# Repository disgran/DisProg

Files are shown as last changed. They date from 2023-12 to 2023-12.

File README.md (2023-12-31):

# DisProg™

DisProg™ es una placa de adaptador USB a serie que se fundamenta en el popular chip CP2102N, incluyendo un circuito de restablecimiento automático ESP32. A diferencia de los módulos económicos que puedes encontrar en Aliexpress, este adaptador destaca por su confiabilidad y versatilidad simultánea. Su confiabilidad se deriva del uso de un conocido chip de adaptador USB a serie proveniente de un proveedor reconocido, y su versatilidad radica en la inclusión del circuito de restablecimiento automático ESP32 IO & EN, eliminando la necesidad de implementarlo en la placa de destino.

Otro punto a favor de DisProg™ es su regulador de voltaje integrado de 3.3V y 500mA, capaz de alimentar el dispositivo que estás programando. Como opción adicional, puedes conectar un cable JST personalizado que facilita la programación segura de relés Shelly sin depender de la alimentación principal. Esto sitúa a DisProg™ como uno de los mejores adaptadores USB/serie para cargar el firmware de tus dispositivos con Tasmota o ESPHome.

Para obtener más detalles sobre este proyecto, te invito a consultar la entrada correspondiente en https://disgran.com/disprog.

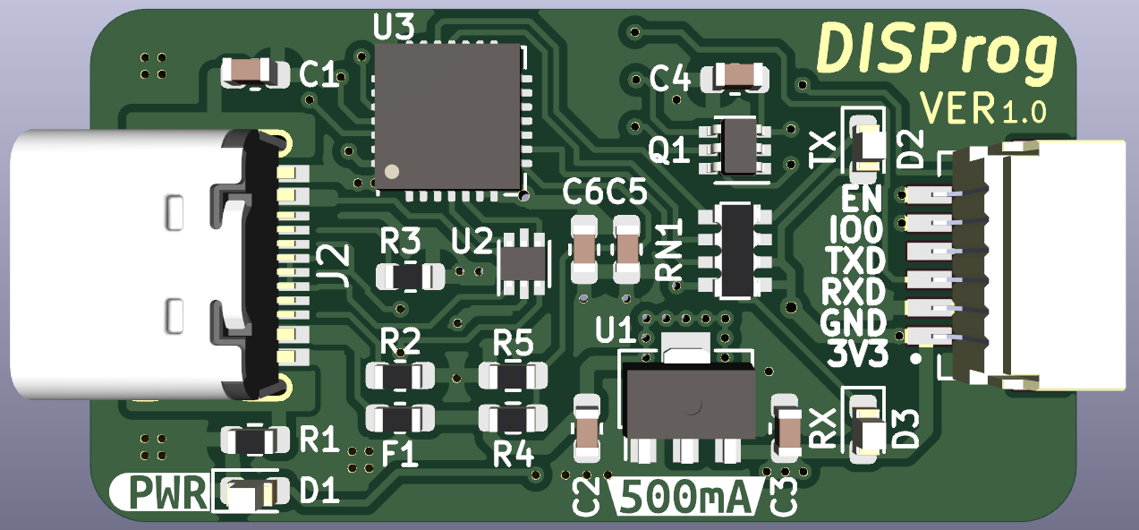
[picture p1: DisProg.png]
Preview_PCB_Terminada


Si estás interesado en adquirir uno de estos adaptadores preensamblados, te invito a visitar mi tienda en https://disgran.com

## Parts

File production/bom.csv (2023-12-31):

Designator | Footprint | Quantity | Value
C1 | 0805 | 1 | 4.7nF
C2 | 0603 | 1 | 1uF
C3 | 0603 | 1 | 10uF
C4 | 0603 | 1 | 1uF
C5 | 0603 | 1 | 10uF
C6 | 0603 | 1 | 0.1uF
D1 | 0603 | 1 | PWR
D2 | 0603 | 1 | TX
D3 | 0603 | 1 | RX
F1 | 0603 | 1 | 0.5A
J1 | JST_SM06B-SRSS-TB_LF__SN_ | 1 | Con_Prog
J2 | USB_C_Receptacle_HRO_TYPE-C-31-M-12 | 1 | USB C
Q1 | SOT-363_SC-70-6 | 1 | UMH3N
R1 | 0603 | 1 | 1M
R2, R3 | 0603 | 2 | 5K1
R4 | 0603 | 1 | 22.1K
R5 | 0603 | 1 | 47.5K
RN1 | R_Array_Convex_4x0603 | 1 | 1K
U1 | SOT-89-3 | 1 | LR1107
U2 | SOT-666 | 1 | USBLC6-2P6
U3 | QFN-28-1EP_5x5mm_P0.5mm_EP3.35x3.35mm | 1 | CP2102N

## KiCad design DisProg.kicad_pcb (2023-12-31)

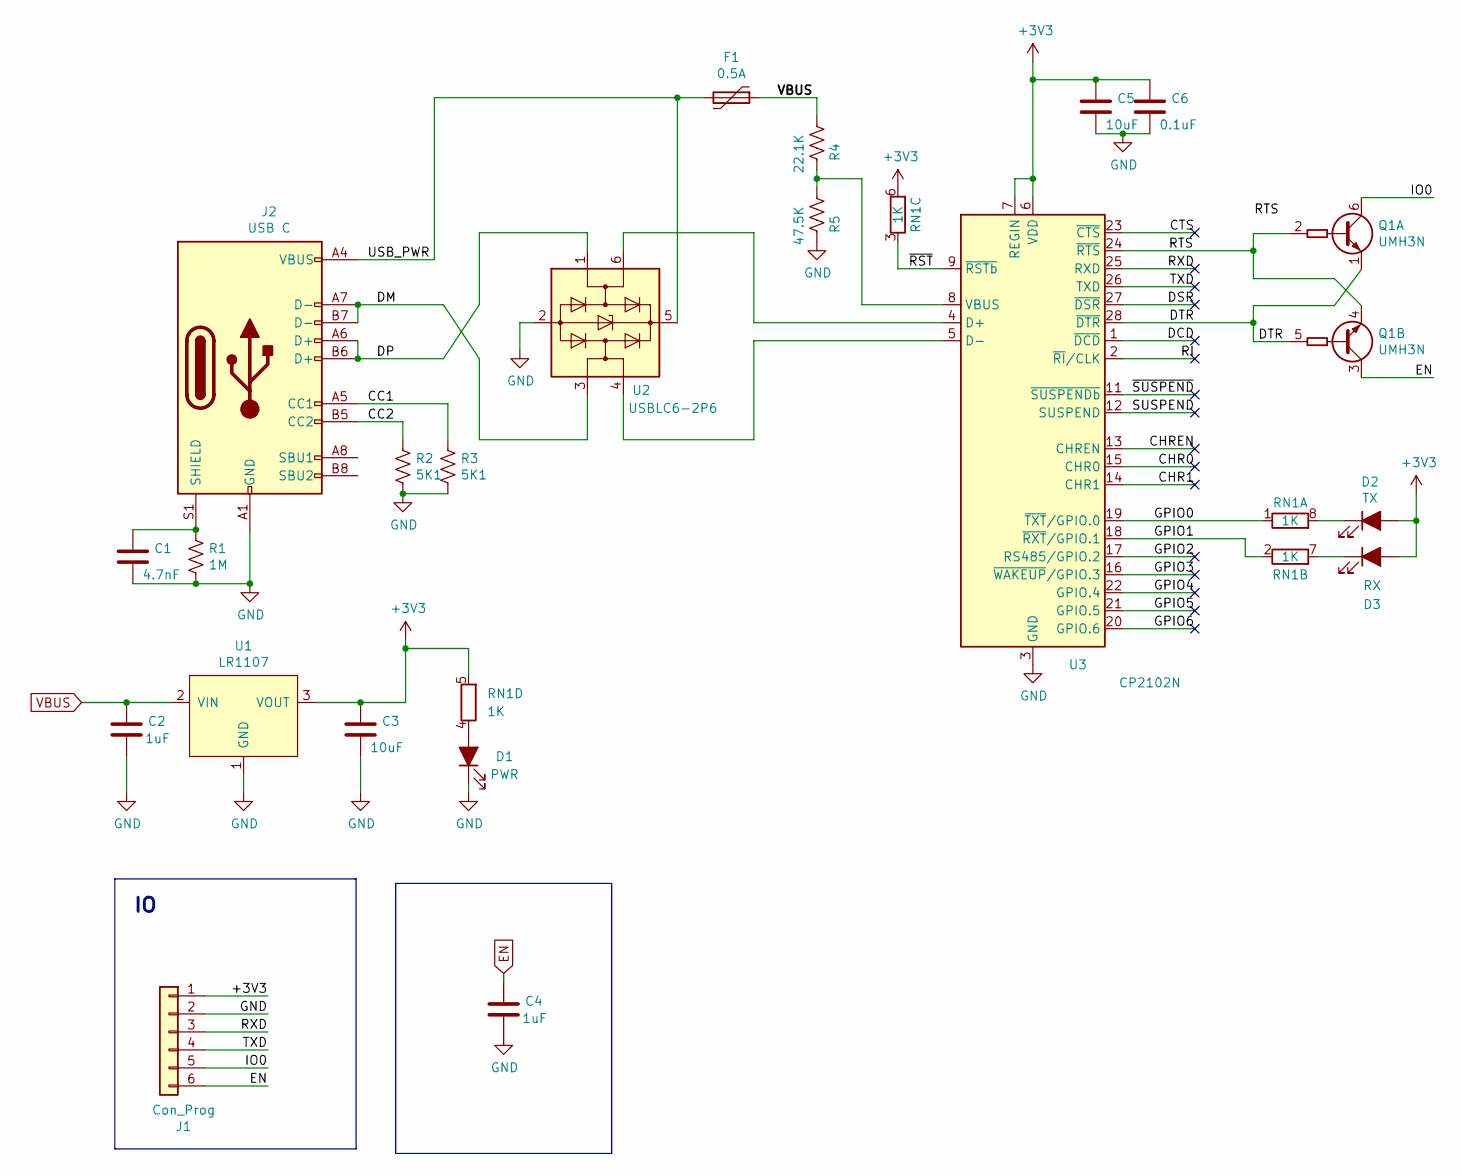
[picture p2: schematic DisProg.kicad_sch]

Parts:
C1: 4.7nF; C_0805_2012Metric; Voltage 50V; LCSC C53987
C2: 1uF; C_0603_1608Metric; LCSC C15849
C3: 10uF; C_0603_1608Metric; LCSC C96446
C4: 1uF; C_0603_1608Metric
C5: 10uF; C_0603_1608Metric; LCSC C19702
C6: 0.1uF; C_0603_1608Metric; LCSC C14663
D1: PWR; LED_0603_1608Metric; LCSC C2286
D2: TX; LED_0603_1608Metric; LCSC C72043
D3: RX; LED_0603_1608Metric; LCSC C2286
F1: 0.5A; Fuse_0603_1608Metric; LCSC C207014
J1: Con_Prog; JST_SM06B-SRSS-TB_LF__SN_; LCSC C160405
J2: USB C; USB_C_Receptacle_HRO_TYPE-C-31-M-12; LCSC C165948
Q1: UMH3N; SOT-363_SC-70-6; LCSC C62892
R1: 1M; R_0603_1608Metric; LCSC C2090547
R2, R3: 5K1; R_0603_1608Metric
R4: 22.1K; R_0603_1608Metric
R5: 47.5K; R_0603_1608Metric
RN1: 1K; R_Array_Convex_4x0603
U1: LR1107; SOT-89-3; LCSC C171498
U2: USBLC6-2P6; SOT-666
U3: CP2102N; QFN-28-1EP_5x5mm_P0.5mm_EP3.35x3.35mm; LCSC C964632

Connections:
+3V3: C3.1, C5.1, C6.1, D2.2 (A), D3.2 (A), J1.1, RN1.5 (R4.2), RN1.6 (R3.2), U1.3 (VOUT), U3.6 (VDD), U3.7 (REGIN)
/CC1: J2.A5 (CC1), R3.1
/CC2: J2.B5 (CC2), R2.1
/CHR0: U3.15 (CHR0)
/CHR1: U3.14 (CHR1)
/CHREN: U3.13 (CHREN)
/CTS: U3.23 (~CTS)
/DCD: U3.1 (~DCD)
/DM: J2.A7 (D-), J2.B7 (D-), U2.3 (I/O2)
/DP: J2.A6 (D+), J2.B6 (D+), U2.1 (I/O1)
/DSR: U3.27 (~DSR)
/DTR: Q1.1 (E1), Q1.5 (B2), U3.28 (~DTR)
/GPIO0: RN1.1 (R1.1), U3.19 (~TXT/GPIO.0)
/GPIO1: RN1.2 (R2.1), U3.18 (~RXT/GPIO.1)
/GPIO2: U3.17 (RS485/GPIO.2)
/GPIO3: U3.16 (~WAKEUP/GPIO.3)
/GPIO4: U3.22 (GPIO.4)
/GPIO5: U3.21 (GPIO.5)
/GPIO6: U3.20 (GPIO.6)
/IO0: J1.5, Q1.6 (C1)
/RI: U3.2 (~RI/CLK)
/RTS: Q1.2 (B1), Q1.4 (E2), U3.24 (~RTS)
/RXD: J1.3, U3.25 (RXD)
/SUSPEND: U3.12 (SUSPEND)
/TXD: J1.4, U3.26 (TXD)
/USB_PWR: F1.2, J2.A4 (VBUS), J2.A9 (VBUS), J2.B4 (VBUS), J2.B9 (VBUS), U2.5 (VBUS)
/~RST: RN1.3 (R3.1), U3.9 (~RSTb)
/~SUSPEND: U3.11 (~SUSPENDb)
EN: C4.1, J1.6, Q1.3 (C2)
GND: C1.2, C2.2, C3.2, C4.2, C5.2, C6.2, D1.1 (K), J1.2, J2.A1 (GND), J2.A12 (GND), J2.B1 (GND), J2.B12 (GND), R1.2, R2.2, R3.2, R5.2, U1.1 (GND), U2.2 (GND), U3.3 (GND), U3.29 (GND)
unnamed: D1.2 (A), RN1.4 (R4.1)
unnamed: D2.1 (K), RN1.8 (R1.2)
unnamed: D3.1 (K), RN1.7 (R2.2)
unnamed: C1.1, J2.S1 (SHIELD), R1.1
unnamed: U2.6 (I/O1), U3.4 (D+)
unnamed: U2.4 (I/O2), U3.5 (D-)
unnamed: R4.2, R5.1, U3.8 (VBUS)
VBUS: C2.1, F1.1, R4.1, U1.2 (VIN)

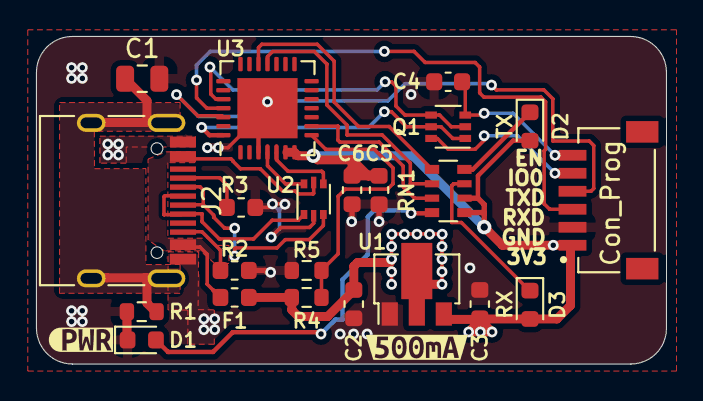
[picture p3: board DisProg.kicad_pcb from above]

Board: 2 copper layers, 35.0 x 18.2 mm, 24 parts (0 on the bottom side), 24 nets.

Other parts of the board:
kibuzzard-62357631: G***; kibuzzard-62357631
kibuzzard-62357776: G***; kibuzzard-62357776
